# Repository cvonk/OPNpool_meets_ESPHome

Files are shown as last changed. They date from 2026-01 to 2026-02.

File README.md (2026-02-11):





> OPNpool Meets ESPHome has been merged with my [original OPNpool](https://github.com/cvonk/OPNpool) repo.  Please refer to that repo instead.

Ever dreamed of making your pool smarter and easier to manage? If you’ve ever owned a backyard pool, you know it’s not just about swimming—there’s a whole world of chemicals, covers, vacuums, brushes, and fiddling with thermostats and circuits. Even with a saltwater pool, you’ve got to keep a close eye on things!

Enter OPNpool: your pool’s new best friend. It takes all the classic pool controller features and brings them into your smart home. OPNpool keeps track of your controller, pump, and chlorinator, so you don’t have to run outside every time you want to check or change something. Even better, you can set up automations—like running the pump longer when it’s hot out—all from the comfort of your phone or smart home dashboard.

Thanks to some clever folks who reverse engineered the RS485 protocol, OPNpool can eavesdrop on the chatter between your pool’s components. The ESP32 inside shares all that state info as JSON/HTTP and can publish it via MQTT. And if you’re a Home Assistant fan, you’ll love how easily it integrates using MQTT Discovery.

# OPNpool meets ESPHome

OPNpool meets ESPHome is an open-source hardware and software solution that brings advanced pool automation to your smart home. By bridging legacy pool controllers with modern IoT platforms, OPNpool enables real-time monitoring, remote control, and seamless integration with Home Assistant. Whether you want to automate your pool pump based on temperature, monitor chlorinator status, or simply enjoy the convenience of remote access, OPNpool provides a robust and extensible platform for pool management.

## How it works

At its core, OPNpool connects an ESP32 microcontroller to your pool controller’s RS-485 bus. The ESP32 runs ESPHome firmware, which translates pool equipment data into Home Assistant entities. This allows you to view and control your pool’s thermostats, pumps, circuits, and chlorinator directly from your smart home dashboard or mobile app. The system is designed for reliability, safety, and ease of installation, with support for over-the-air updates and waterproof enclosures for outdoor use.

## Features

- [x] **Smart Home Integration:** Native support for Home Assistant and ESPHome.
- [x] **Remote Monitoring & Control:** Access your pool’s status and controls from anywhere.
- [x] **Community Driven:** Built on the work of pool automation enthusiasts and reverse engineers.
- [x] **Open Source:** Fully transparent hardware and software—customize and extend as needed.

## Getting started

No prior experience with pool automation or ESPHome is required. The documentation below will guide you through hardware assembly, wiring, firmware installation, and Home Assistant integration. If you have questions or need help, join the project’s GitHub Discussions for community support.

This device was tested with the Pentair SunTouch controller with firmware **2.080** (2013-07-15), connected to an IntelliFlo pump and IntelliChlor saltwater chlorinator.

> This open source and hardware project is intended to comply with the October 2016 exemption to the Digital Millennium Copyright Act allowing "good-faith" testing," in a controlled environment designed to avoid any harm to individuals or to the public.

## Acknowledgements

> We proudly acknowledge the work of reverse engineering pioneers [Joshua Bloch](https://docs.google.com/document/d/1M0KMfXfvbszKeqzu6MUF_7yM6KDHk8cZ5nrH1_OUcAc/edit), [Michael Russe](http://cocoontech.com/forums/files/file/173-pab014sharezip/), and [George Saw](http://cocoontech.com/forums/topic/27864-download-pitzip/). (Drop me a line if I forgot you.)

## Usage

Start with [installing the ESPHome environment](https://esphome.io/guides/installing_esphome/) on a beefy computer. In my case, this cut the compilation time to a minute, compared to half an hour when running it as an add-on to Home Assistant.

In an empty directory, create a `opnpool-1.yaml` configuration file as shown below.
```yaml
substitutions:
  device_name: opnpool-1
  friendly_name: "OPNpool meets ESPHome"
  description: "External component, see https://github.com/cvonk/OPNpool_meets_ESPHome"

esphome:
  name: ${device_name}
  comment: ${description}
  friendly_name: ${friendly_name}

esp32:
  variant: esp32c6          # or esp32     for <= r3 boards
  board: esp32-c6-devkitc-1 # or lolin_d32 for <= r3 boards
  framework:
    type: esp-idf

wifi:
  domain: !secret domain_name # only needed if not on the same subnet
  min_auth_mode: WPA2
  reboot_timeout: 0s
  networks:
  - ssid: !secret wifi_ssid
    password: !secret wifi_password

api:

ota:
  - platform: esphome
    password: !secret ota_password

external_components:
  - source: github://cvonk/OPNpool_meets_ESPHome
    components: [ opnpool ]

logger:
  level: VERBOSE          # build includes ESP_LOGx up to VERBOSE
  initial_level: WARN     # only show up to WARN globally
  logs:
    poolstate_rx: VERBOSE # show decoded messages

opnpool:
  id: opnpool_1
  RS-485:
    tx_pin:  21  # or 26 for <= r3 boards 
    rx_pin:  22  # or 25 for <= r3 boards
    rts_pin: 23  # or 27 for <= r3 boards
```

Specify your own secrets in `secrets.yaml`

```yaml
wifi_ssid: "REDACTED"
wifi_password: "REDACTED"
domain_name: ".iot.example.com" # appended to base fname to create FQDN for OTA updates
ota_password: "REDACTED"
api_encryption_key: "REDACTED"
```

Compile and upload the code using

```bash
esphome run opnpool-1.yaml
```

The first time, you need to upload over USB Serial, but after that you can use over-the-air updates.

In the output, you should see something like:

```text
[16:26:54.983]I (423) boot: Loaded app from partition at offset 0x10000
[16:26:55.024]I (465) boot: Set actual ota_seq=1 in otadata[0]
[16:26:55.029]I (465) boot: Disabling RNG early entropy source...
[16:26:55.268][W][component:333]: api set Warning flag: unspecified
[16:26:55.273][W][component:342]: wifi set Warning flag: scanning for networks
[16:27:01.293][W][component:373]: wifi cleared Warning flag
[16:27:25.143][E][RS-485:108][pool_req_task]: tx_q full
[16:27:55.144][E][RS-485:108][pool_req_task]: tx_q full
```

In the above trace, the `tx_q full` indicates that it can't transmit to the pool controller.

If you haven't already, add the ESPHome integration to Home Assistant.



Under Integrations, you will find now notice that Home Assistant auto discovered your new device.



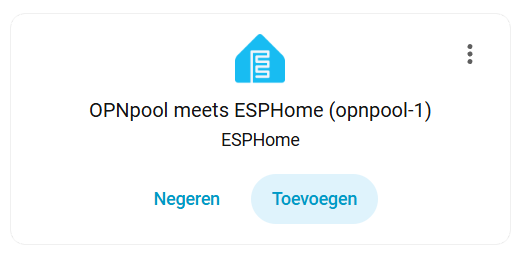
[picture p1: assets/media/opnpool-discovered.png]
Discovered


Add it, and specify your API key.  Name the device and assign it an area. You should then see the enities although their values are `unknown`.  Time to populate those entities by connecting it to the pool controller ;-)

## Connect

At the core this project is an ESP32 module and a 3.3 Volt RS-485 adapter. You can
breadboard this using:

* Any ESP32 module that has an USB connector and three GPIO pins available.
* Any "Max485 Module TTL". To make it 3.3 Volt compliant, change the chip to a `MAX3485CSA+`. While you're at it, you may as well remove the 10 kΩ pullup resistors (typically labeled `R1` to `R4`).
* A piece of Cat5 ethernet cable to connect to the pool controller.

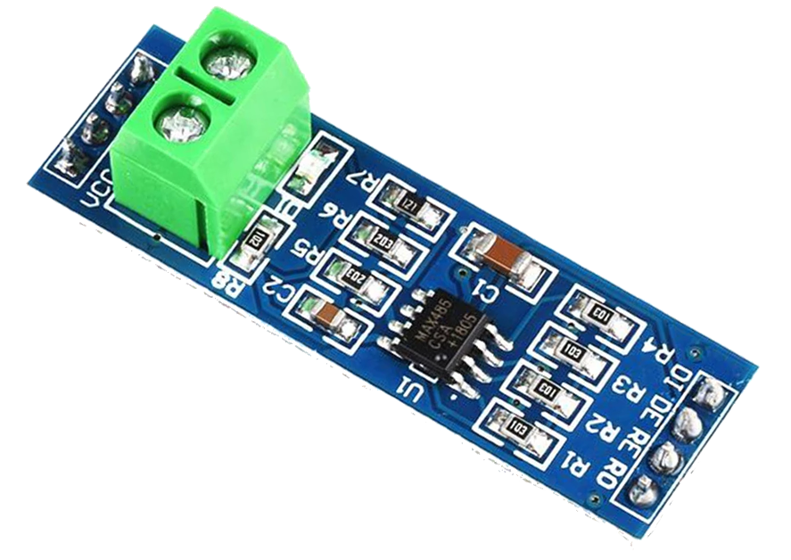
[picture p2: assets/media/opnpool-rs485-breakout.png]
Inside of Pool controller


If you prefer to make this a more permanent solution, I suggest rolling a printed circuit board and housing it in a IP68 waterproof case with IP68 connectors.  More about this later.

> :warning: **THIS PROJECT IS OFFERED AS IS. IF YOU USE IT YOU ASSUME ALL RISKS. NO WARRANTIES. At the very least, turn off the power while you work on your pool equipment. Be careful, THERE IS ALWAYS A RISK OF BREAKING YOUR POOL EQUIPMENT.**

Understanding the above warning .. the RS-485 header can be found on the back of the control board. There are probably already wires connected that go to the devices such as pump and chlorinator.

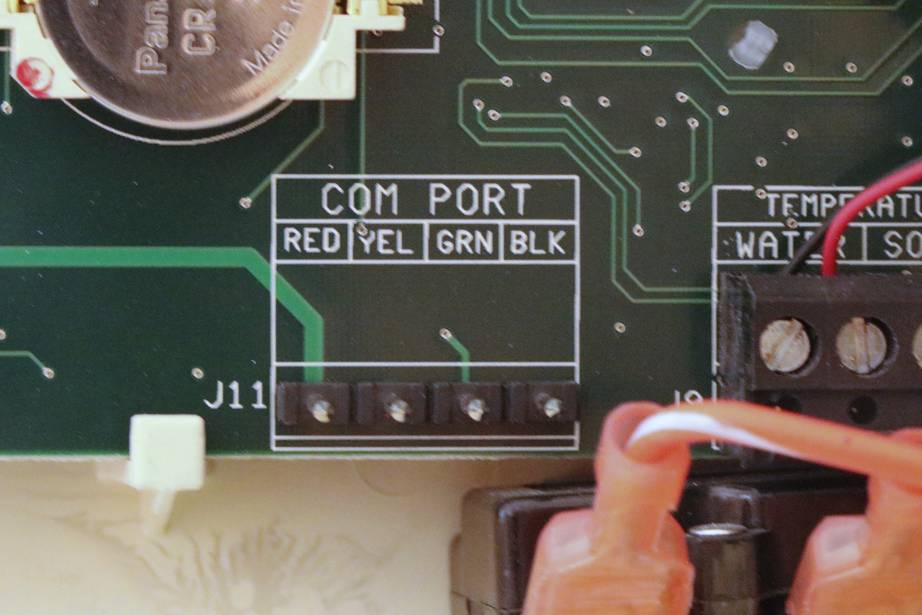
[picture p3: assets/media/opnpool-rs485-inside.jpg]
Inside of Pool controller


To minimize electromagnetic interference, use a twisted pairs from e.g. CAT-5 cable to connect the `A`/`B` pair to the RS-485 adapter as shown in the table below.

| Controller | RS-485 adapter | idle state | 
|:---|:---:|:---|
| `-DATA` (green)  |  `A` | negative |
| `+DATA` (yellow) |  `B` | positive |

Connect the RS-485 adapter to the ESP32 module.  I also pulled `GPIO#27` down with a 10 k&ohm; resistor, to keep it from transmiting while the ESP32 is booting.

| RS-485 adapter | ESP32 module |
|:---|:---|
| RO | `GPIO#25` |
| DI | `GPIO#26` |
| DE and RE | `GPIO#27` |
| GND | `GND` |

The serial monitor will start to show decoded messages such as:

```json
{CTRL_VERSION_REQ: {}}
{CTRL_VERSION_RESP: {"firmware":"2.80"}}
{CTRL_TIME_REQ: {}}
{CTRL_TIME_RESP: {"tod":{"time":"18:51","date":"2026-01-18"}}}
{CTRL_HEAT_REQ: {}}
{CTRL_HEAT_RESP: {"thermos":{"POOL":{"temp":54,"sp":63,"src":"NONE"},"SPA":{"temp":54,"sp"}
```

> :bulb: If you don't see such messages, make sure you didn't swap the data leads, or oddly enough some people report that they do need to swap the data leads.  To debug the datalink framing, set the `datalink_rx` logger level to `VERBOSE` and build and upload the code again. See futher below.

In Home Assistant the entities should populate, and show on your favorite Lovelace UI.

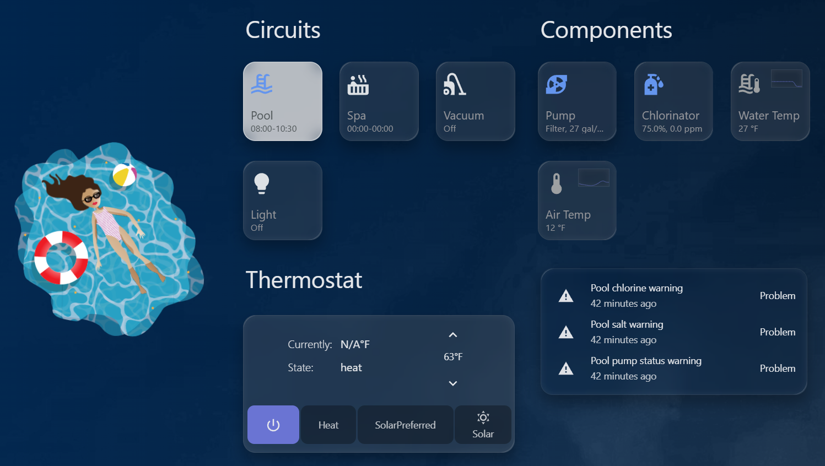
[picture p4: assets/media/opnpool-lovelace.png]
Lovelace_view


## PCB

For a robust and weatherproof installation, we recommend building a custom printed circuit board (PCB) to house the ESP32-C6 module, RS-485 adapter, and DC/DC converter. This approach ensures reliable connections, easier mounting, and long-term durability—especially for outdoor or poolside environments.

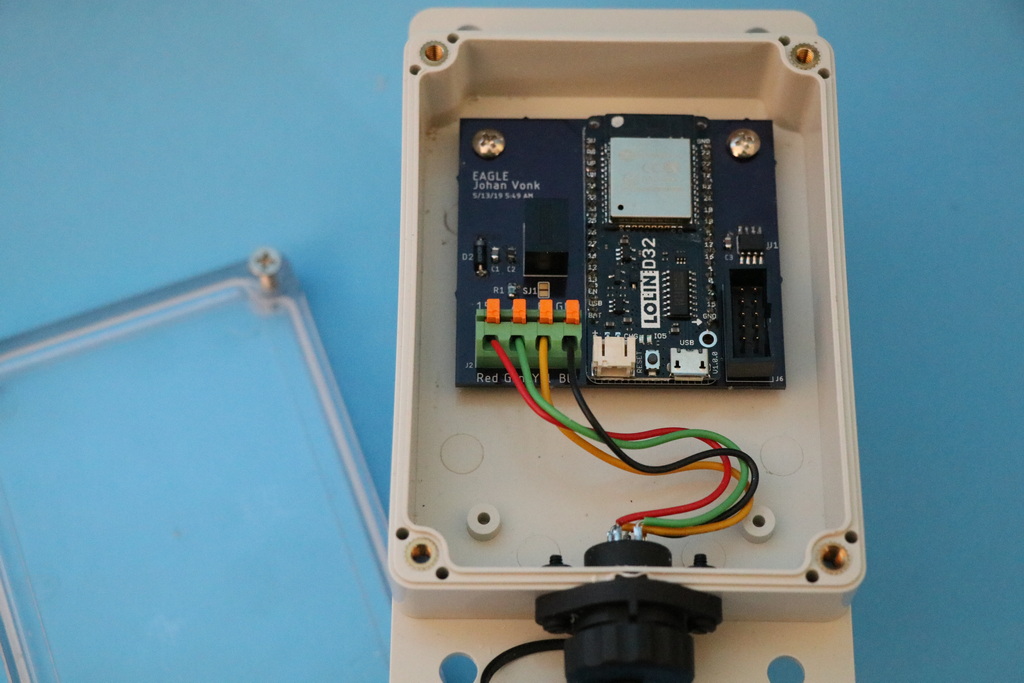
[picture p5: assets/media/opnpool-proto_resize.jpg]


Note that the photo above is from a rev 1 board.

### Schematic

The hardware design features a buck converter that supplies 5V to the `5V0` pin on the ESP32-C6 DevKitC-1-N8 daughterboard. The scotty diode prevent issues when the board is also powered via USB.

Schematic

The main data path runs between the RS-485 connector and the ESP32-C6 on the DevKitC-1-N8. An optional termination resistor is included to minimize signal reflections on the RS-485 bus.

### Board Layout

The entire schematic fits comfortably on a compact two-layer PCB. The board was designed using the free version of AutoDesk EAGLE, and all source files — including layout and schematics — are available in the [hardware directory](tree/main/hardware) of this repository.

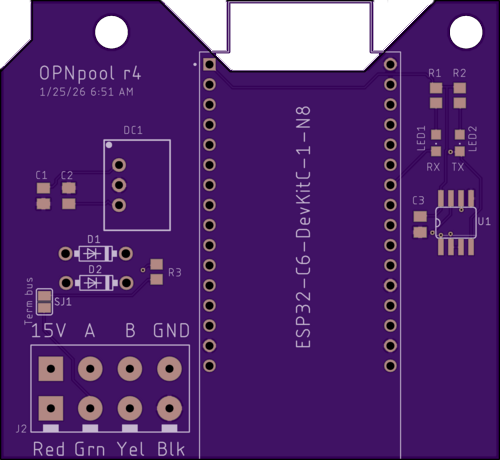
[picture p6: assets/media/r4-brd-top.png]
Board Layout


### Bill of materials

| Name | Description | Suggested mfr/part# | Price paid
|---|---|---|---
| PBC r4 | Printed circuit board | OSHPark | [$9.43](https://oshpark.com/)
| Enclosure | 158x90x60mm ABS Plastic Junction Box, IP65 | *white label* | [$9.81](https://www.harfington.com/products/p-1159792)
| RS-485_CONN | 5P Plug+socket, 5-pin, 16mm aviation, IP68 | SP16 5P | [$3.98](https://www.aliexpress.us/item/2251832722757291.html)
| RS-485-TERM | Fixed terminal block, 4-pin, screwless, 5 mm pitch | Phoenix-Contact 1862437 | [$2.02](https://www.digikey.com/en/products/detail/phoenix-contact/1862437/6605421)
| ESP32-C6 DevKitC-1-N8 | ESP32-C6 dev board with 8MB flash, based on ESP32-C6-WROOM | ESP32-C6 DevKitC-1-N8 | [$9.00](https://www.digikey.com/en/products/detail/espressif-systems/ESP32-C6-DEVKITC-1-N8/17728861)
| MAX3485 | Maxim MAX3485CSA, RS-485/UART interface IC 3.3V, 8-SOIC  | Analog-Devices MAX3485CSA+T | [$5.64](https://www.digikey.com/en/products/detail/analog-devices-inc-maxim-integrated/MAX3485CSA-T/1703654)
| DC1 | DC/DC Converter R-78E5.0-0.5, 7-28V to 5V, 0.5A, 3-SIP | RECOM-Power R-78E5.0-0.5 | [$3.30](https://www.digikey.com/en/products/detail/recom-power/R-78E5-0-0-5/2834904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)
| D1, D2 | Schottky Diode, 1N5818, 30V, 1A, DO-41 | Diodes Incorporated 1N5818-T | [$0.30](https://www.digikey.com/en/products/detail/diodes-incorporated/1N5818-T/22054)
| LED1 | LED, Green Clear 571nm, 1206 | Lite-On LTST-C150KGKT | [$0.15](https://www.digikey.com/en/products/detail/diodes-incorporated/1N5818-T/22054)
| LED2 | LED, Amber Clear 602nm, 1206 | Lite-On LTST-C150AKT | [$0.15](http2s://www.digikey.com/en/products/detail/liteon/LTST-C150AKT/269213?s=N4IgTCBcDaIDIEsAuBTAtAeQHYAI4BUBlfNAYQEYBWABgEEBpfEAXQF8g)
| C1, C2 | Capacitor, 10 µF, 25 V, multi-layer ceramic, 0805 | KEMET C0805C106K3PACTU | [$0.22](https://www.digikey.com/en/products/detail/kemet/C0805C106K3PACTU/5267604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)
| C3 | Capacitor, 0.1 µF, 6.3 V, multi-layer ceramic, 0805 | KEMET C0805C104M3RACTU | [$0.12](https://www.digikey.com/en/products/detail/kemet/C0805C104M3RACTU/2211748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)
| R1, R2 | Resistor, 68 Ω, 1/8 W, 0805 | YAGEO RC0805FR-0768RL | [$0.20](https://www.digikey.com/en/products/detail/yageo/RC0805FR-0768RL/728097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)
| R3 | Not stuffed, resistor, 120 Ω, 1/4 W, 0805 | KAO SG73S2ATTD121J | [$0.00](https://www.digikey.com/en/products/detail/koa-speer-electronics-inc/RK73B2ATTD121J/10236600)
| PCB Screws  | Machine screw, #6-32 x x 3/16", panhead | Keystone-Electronics 9306  | [$0.10](https://www.digikey.com/en/products/detail/keystone-electronics/9306/2746085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)
| CONN Screws | Machine screw, M2-0.4 x 16 mm, cheese head | Essentra 50M020040D016 | [$0.28](https://www.digikey.com/en/products/detail/essentra-components/50M020040D016/11639297)
| CONN Nuts | Hex nut, M2-0.4, nylon | Essentra 04M020040HN | [$0.15](https://www.digikey.com/en/products/detail/essentra-components/04M020040HN/9677098)

Note that tariffs and shipping will add to the cost.

## Troubleshooting

Not all controller firmwares are created equally.  If you are not using firmware version 2.080, you will need dive down to the byte level and to tweak the network layer.  If you succeed, please send me an pull request, and I will iinclude it in the next release.

To show more (or less) debug information, specify the levels in `opnpoool-1.yaml`

```yaml
logger:
  level: VERBOSE       # build includes ESP_LOGx up to VERBOSE
  initial_level: WARN  # only show up to WARN globally
  logs:
    rs485: WARN
    datalink_rx: WARN
    datalink_tx: WARN
    network_rx: WARN
    network_create: WARN
    pool_task: WARN
    ipc: WARN
    poolstate: WARN
    poolstate_rx: VERBOSE
    opnpool: WARN
    opnpool_climate: WARN
    opnpool_switch: WARN
    opnpool_sensor: WARN
    opnpool_binary_sensor: WARN
    opnpool_text_sensor: WARN
    enum_helpers: WARN
```

For the `logger` component, it is recommended to use the following levels: `WARN`, which shows only warnings and errors; `INFO`, which includes informational messages such as configuration details, warnings, and errors; and `VERBOSE`, which provides very detailed logs, info, warnings, and errors. Be careful not to enable too much logging, as excessive output can negatively impact the connection between Home Assistant and the ESP32-C6.

### Decoding Stack Traces

If your ESP32-C6 crashes and you notice stack traces in the serial log, you can simplify debugging by enabling ESPHome's stack trace decoder. With this feature, exception addresses are automatically translated into human-readable function names and line numbers within your logs.

To activate the stack trace decoder, add the following lines to your YAML configuration:

```yaml
debug:
  update_interval: 5s  # for exception decoding in logs
```

> **Tip:** Detailed crash information will only appear on the serial console (not in the web logs). Be sure to check the serial output for troubleshooting.

# FAQ

**LEDs not blinking with RS-485 connected**

If communication fails, swap the `-DATA` and `+DATA` wires, as standards for these labels vary. 

**Is a controller required?**

This setup ensures that when selling the house, the next owner is not stuck with a "custom" system. They can use the pool conventionally or easily adopt the smart features.  If you're determined to build your own controller, I can recommend Russ Goldin's [nodejs-poolController](https://github.com/tagyoureit/nodejs-poolController/tree/master).

**Will it work with ___ board?**

There are many boards and kits that incorporate the ESP32. I started with the ESP8266, switched to the original ESP32, and use the ESP-C6. At this point it probably runs on any ESP32 flavor board. If you want to try something else, sure feel free the code is written to be portable. Just make sure you use the MAX3485 instead of the TTL-level MAX485.

**My firmware is ___ How do you update SunTouch firmware?**

Instead of taking such a risky step, I recommend enabling `VERBOSE` logging for `datalink_rx` and `network_rx`.  This will visualize the raw bytes received and messages interpretated. Compare that with the structures `network_msg.h`, and update the file as needed.

> Only do this if you very confident with flashing electronics. You risk bricking your pool controller.

Having read the above warning, you can upgrade if your controller is at [version 2.x](https://saturationregion.blogspot.com/2020/01/whats-deal-with-easytouch-versions-1.html). You will need to get a [USBDM JS16](https://www.aliexpress.us/w/wholesale-Freescale-USBDM-Programmer-JS16.html?spm=a2g0o.detail.search.0) programmer, [make](https://www.troublefreepool.com/threads/how-to-perform-firmware-upgrade-on-pentair-controllers.69589/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) a [JST cable](https://www.aliexpress.us/w/wholesale-5-PCS-JST-1.-25mm-Male-Female-6p.html?spm=a2g0o.detail.search.0) following [the instructions](https://www.troublefreepool.com/threads/how-to-perform-firmware-upgrade-on-pentair-controllers.69589/page-7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).

#
I hope this project brings you joy.  Keep in touch through the dicussion forum.

Coert

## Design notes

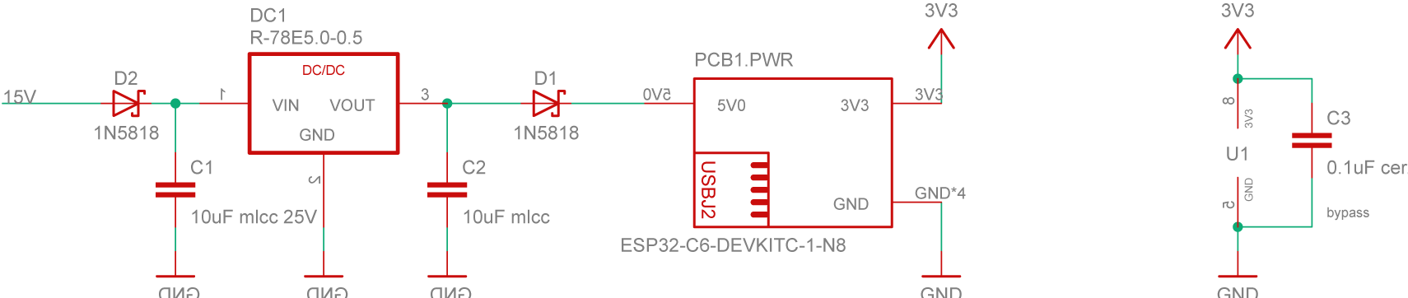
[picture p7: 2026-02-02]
assets/media/schematic-r4-pwr.png

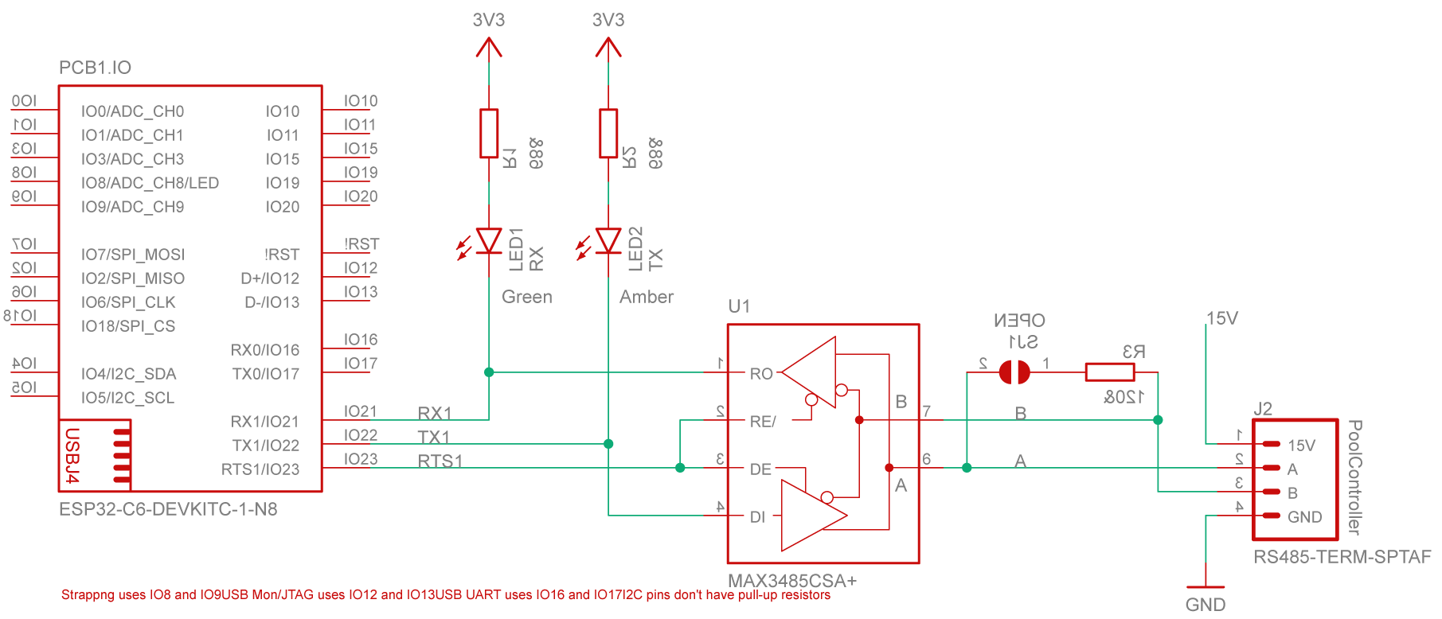
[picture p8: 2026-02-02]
assets/media/schematic-r4-io.png

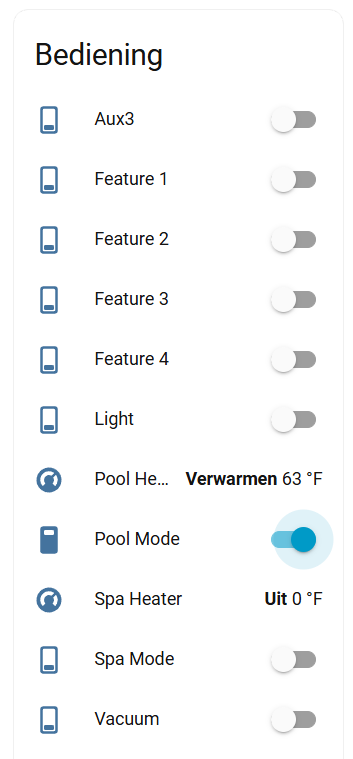
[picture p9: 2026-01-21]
assets/media/opnpool-bediening.png

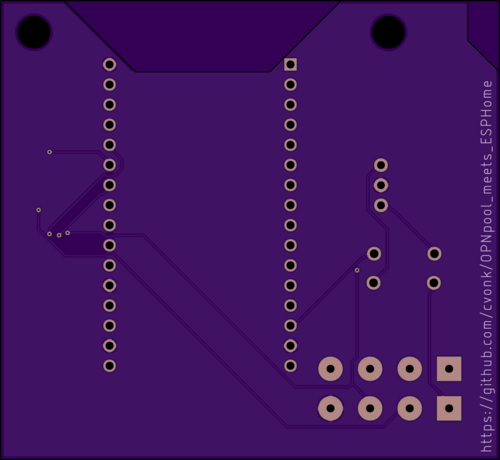
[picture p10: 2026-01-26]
assets/media/r4-brd-bottom.png

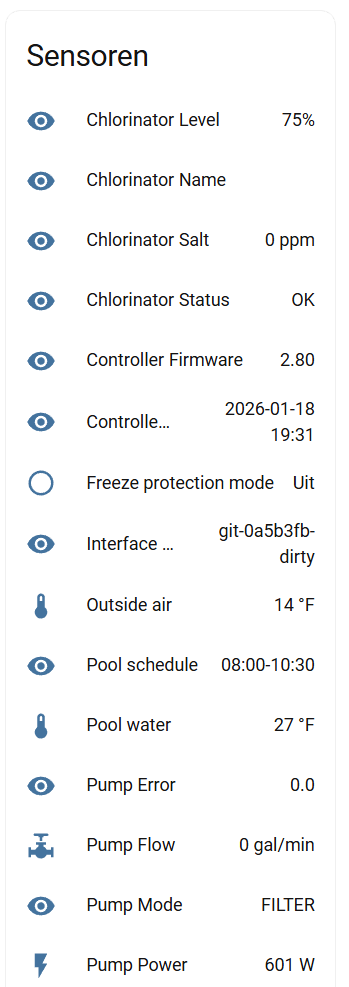
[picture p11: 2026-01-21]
assets/media/opnpool-sensoren.png

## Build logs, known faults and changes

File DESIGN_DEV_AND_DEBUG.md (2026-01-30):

# Design, development and debugging

This software is designed for robustness, reliability, and long-term maintainability. The architecture emphasizes modularity and extensibility through protocol abstraction helpers and FreeRTOS primitives for cooperative task scheduling and inter-task communication. Comprehensive logging enables diagnostics, troubleshooting, and protocol analysis.

## Design

ESPHome provides a single-threaded environment, so explicit thread safety measures are not required.

### Protocol stack

The software follows a layered architecture where each component builds upon the one below it, creating a clean path from raw electrical signals to Home Assistant entities. Here's how data flows through the system:

1. **MAX3485CSA+** — At the physical layer, this integrated circuit performs the critical job of converting between the ESP32's logic-level signals and the differential signaling used by RS-485. This conversion enables robust, noise-resistant communication over long twisted-pair cable runs to your pool equipment.

2. **UART** — The ESP32's Universal Asynchronous Receiver/Transmitter bridges the gap between bit streams and bytes. It frames each byte with start and stop bits, manages precise timing at the configured baud rate, and delivers clean byte streams to the software layers above.

3. **RS-485 driver** — This layer wraps the UART hardware with a practical interface for half-duplex RS-485 communication. Beyond basic UART configuration and GPIO control, it maintains a transmit queue for outgoing packets and exposes function pointers that let higher layers easily interact with the bus. The driver's two essential operations are reading incoming bytes and queueing outgoing byte streams for transmission.

4. **Data Link Layer (DLL)** — Here's where raw bytes become structured packets. On reception, the DLL strips headers and tails from RS-485 byte streams and validates their integrity. On transmission, it wraps outgoing data with the proper framing to ensure packets arrive intact.

5. **Network Layer** — This layer speaks the pool controller's language, translating between raw datalink packets and meaningful network messages. Incoming packets become structured messages the application can understand; outgoing messages get encapsulated into properly formatted datalink packets ready for the wire.

6. **PoolState** — Think of this as the software's digital twin of your pool system. This class maintains a complete model of the pool controller and all its peripherals—pump, chlorinator, circuits, sensors, and more. Every incoming network message updates this state, keeping it synchronized with the actual equipment. This real-time model forms the foundation for all sensor readings and control operations.

7. **OpnPool** — The final layer bridges the protocol stack to the ESPHome world. It continuously synchronizes the PoolState with ESPHome entities, ensuring your Home Assistant dashboard accurately reflects your pool's status. When you flip a switch or adjust the temperature in Home Assistant, this layer translates your intent into commands for the pool controller. Conversely, it publishes state changes as updates to climate controls, switches, sensors, binary sensors, and text sensors.

### Tasks

Rather than cramming everything into a single execution thread, the software leverages FreeRTOS to divide responsibilities between two cooperative tasks that communicate through message-passing mailboxes:

* The **main task** orchestrates the high-level application logic, running OpnPool and PoolState to manage state and interact with ESPHome.
* The **pool task** handles the nitty-gritty details of RS-485 communication, protocol parsing, and network message processing. It even spawns its own helper task dedicated to periodically requesting updates from the pool controller.

This separation keeps low-level communication concerns isolated from application logic, making the codebase easier to reason about and maintain.

### More info

Want to dive deeper into the protocol and architecture? The [original OPNpool project](https://github.com/cvonk/OPNpool) has comprehensive design documentation that applies equally well to this ESPHome port:

- [OPNpool Design Documentation Overview](https://coertvonk.com/category/sw/embedded/opnpool-design)

These chapters are particularly relevant:

- [RS-485 bus](https://coertvonk.com/sw/embedded/opnpool-design/bus-access-31957) — Low-level bus access and timing
- [Hardware](https://coertvonk.com/sw/embedded/opnpool-design/hardware-3-31959) — Circuit design and interfacing
- [Protocol](https://coertvonk.com/sw/embedded/opnpool-design/protocol-31965) — Message format and state machine details

## Development

For the best development experience, install the C/C++ and [ESPHome extension](https://marketplace.visualstudio.com/items?itemName=ESPHome.esphome-VSCode) in VS Code.

Clone the repository to a local directory:
```bash
git clone https://github.com/cvonk/OPNpool_meets_ESPHome.git
```

Or using SSH:
```bash
git clone git@github.com:cvonk/OPNpool_meets_ESPHome.git
```

The included `tasks.json` file provides pre-configured build and upload tasks that integrate seamlessly with VS Code. Build output maps directly to your project files, letting you jump straight to errors and warnings from the `Problems` tab.

**Common shortcuts:**

- **Build:** <kbd>Ctrl</kbd>+<kbd>Shift</kbd>+<kbd>B</kbd> (or <kbd>Cmd</kbd>+<kbd>Shift</kbd>+<kbd>B</kbd> on Mac)
- **Compile & Upload:** <kbd>Ctrl</kbd>+<kbd>Shift</kbd>+<kbd>P</kbd> → "Run Task" → "ESPHome Upload opnpool-1"
- **Clean:** <kbd>Ctrl</kbd>+<kbd>Shift</kbd>+<kbd>P</kbd> → "Run Task" → "ESPHome Clean opnpool-1"
- **View Logs:** <kbd>Ctrl</kbd>+<kbd>Shift</kbd>+<kbd>P</kbd> → "Run Task" → "ESPHome Logs opnpool-1"

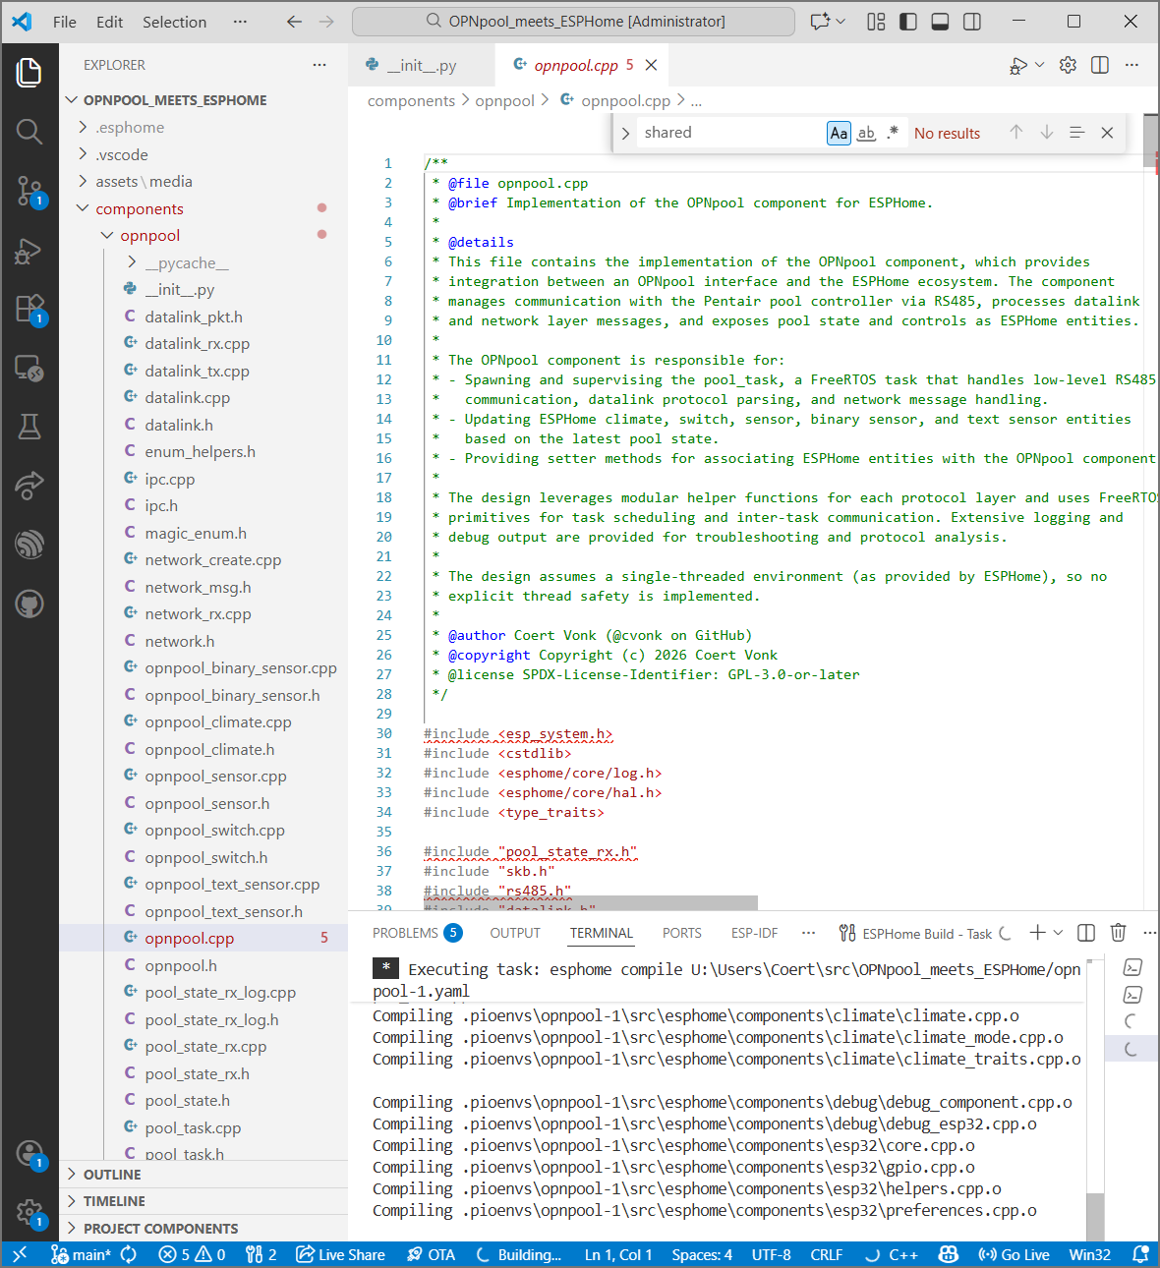
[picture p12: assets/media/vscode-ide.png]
VSCode_ide


## JTAG debugging (on &ge; r4 boards)

The newer r4 boards feature the ESP32-C6 module with built-in JTAG debugging capability. This eliminates the need for external debugging hardware—just connect directly via USB. The configuration is straightforward:

```
build_type = debug
monitor_speed = 115200
debug_tool = esp-builtin
debug_init_break = tbreak setup ; or e.g. app_main
```

You may also want to disable optimizations for clearer debugging:
```
debug_build_flags = -O0 -g -ggdb
```

On Windows, Zadig might need to reassign Interface 2 to WinUSB 6.xx for proper operation.

## JTAG debugging (on &le; r3 boards)

While `ESP_LOGx` logging serves its purpose, it traps you in an endless cycle of adding print statements, recompiling, uploading, and hoping you logged the right thing. JTAG debugging with GDB breaks this cycle completely. You get direct, real-time access to your ESP32's internal state—set breakpoints anywhere, inspect the full call stack, examine local variables, and watch memory locations change, all without modifying a single line of code or recompiling.

Memory corruption bugs that take hours to track down with logging? Set a watchpoint on the corrupted address and GDB will halt execution the instant something writes to it, showing you exactly what code is responsible. This is the difference between guessing and knowing—JTAG transforms ESP32 development from a frustrating debug-by-printf experience into professional source-level debugging.

### ESP-Prog

The ESP-Prog is your gateway to JTAG debugging on r3 and earlier boards. This compact debugging tool connects the 10-pin JTAG header on your OPNpool PCB to your computer, unlocking hardware-level debugging and programming capabilities that simply aren't available through the standard USB serial connection.

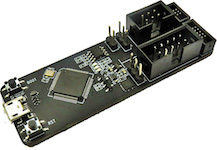
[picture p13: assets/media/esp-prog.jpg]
ESP-Prog


Beyond debugging, the ESP-Prog can also flash firmware and provide serial communication—meaning you can disconnect your regular USB cable entirely during debug sessions.

At its heart, the ESP-Prog uses an FTDI FT2232HL chip that exposes two independent USB channels: one for JTAG and another for serial communication. Getting started requires installing the FTDI driver per the [PlatformIO instructions](https://docs.platformio.org/en/stable/plus/debug-tools/esp-prog.html#drivers)—read them carefully, as there's a crucial driver modification step.[^1]

[^1]: The driver exposes both channels as serial ports. Channel 1 handles standard serial communication, while channel 0 serves JTAG. For JTAG to work, you must unload the serial driver from channel 0—on Windows, this means using Zadig to replace the FTDI driver with the Microsoft WinUSB generic driver.

### VSCode

Start by cloning the code from GitHub and performing a regular compile as described in the Development section. This generates a PlatformIO build directory at `.esphome/build/opnpool-1` containing all the generated C++ code, component sources, and ESPHome dependencies.

Open a fresh VS Code window and install the `PlatformIO IDE` extension if you haven't already. Navigate to the `.esphome/build/opnpool-1` folder and open it in VS Code. Then append these configuration lines to your `platformio.ini` file:

```
build_type = debug
monitor_speed = 115200
debug_init_break = tbreak setup
debug_tool = custom
debug_port = localhost:3333
```

Give VS Code a moment to update its metadata—proceeding too quickly will trigger a "Could not find the specified task" error. Once ready, connect your ESP-Prog to the computer and attach the 10-pin ribbon cable to the OPNpool PCB (keep the cable short to minimize signal integrity issues).

> **Note:** Theoretically, `debug_tool = esp-prog` should work without the `custom` override and manual OpenOCD startup. In practice, you'll likely encounter `.pioinit:11: Error in sourced command file` errors. The `.pioinit` file is auto-generated with target-specific defaults, and PlatformIO's automatic configuration doesn't always get it right.

OpenOCD (Open On-Chip Debugger) acts as the bridge between your IDE and the ESP32 hardware. Launch it manually and wait for the connection to establish:

```bash
cd ".platformio\packages\tool-openocd-esp32\bin"
./openocd -f board/esp32-wrover-kit-3.3v.cfg
```

Now for the fun part. Open the source file you want to debug in VS Code and click next to a line number to set a breakpoint—you'll see a red circle appear. For this example, we'll break in the PoolState constructor.

Click the "Run and Debug" icon in the activity bar, then hit the green play button in the top-left corner. Watch the `Terminal` panel as compilation proceeds. Once complete, switch to the `Debug Console` and wait while it connects to OpenOCD and loads all the symbolic debugging information.

When everything's ready, you'll see something like:

```
Thread 2 "loopTask" hit Temporary breakpoint 1.15, setup () at src/main.cpp:67
67	void setup() {
```

You're now wielding the full power of GDB. Inspect variables, navigate the call stack, and use the `Debug` view to explore program state interactively. Want to catch memory corruption? Set a watchpoint on the specific address you suspect is being corrupted:

```gdb
print &last_
   $4 = (esphome::opnpool::poolstate_t *) 0x3ffc19c0
watch *(0x3ffc19c0)
   Hardware watchpoint 4: *(0x3ffc19c0)
continue
```

Execution will halt the instant anything writes to that memory location, showing you exactly what code is responsible. This is debugging as it should be.

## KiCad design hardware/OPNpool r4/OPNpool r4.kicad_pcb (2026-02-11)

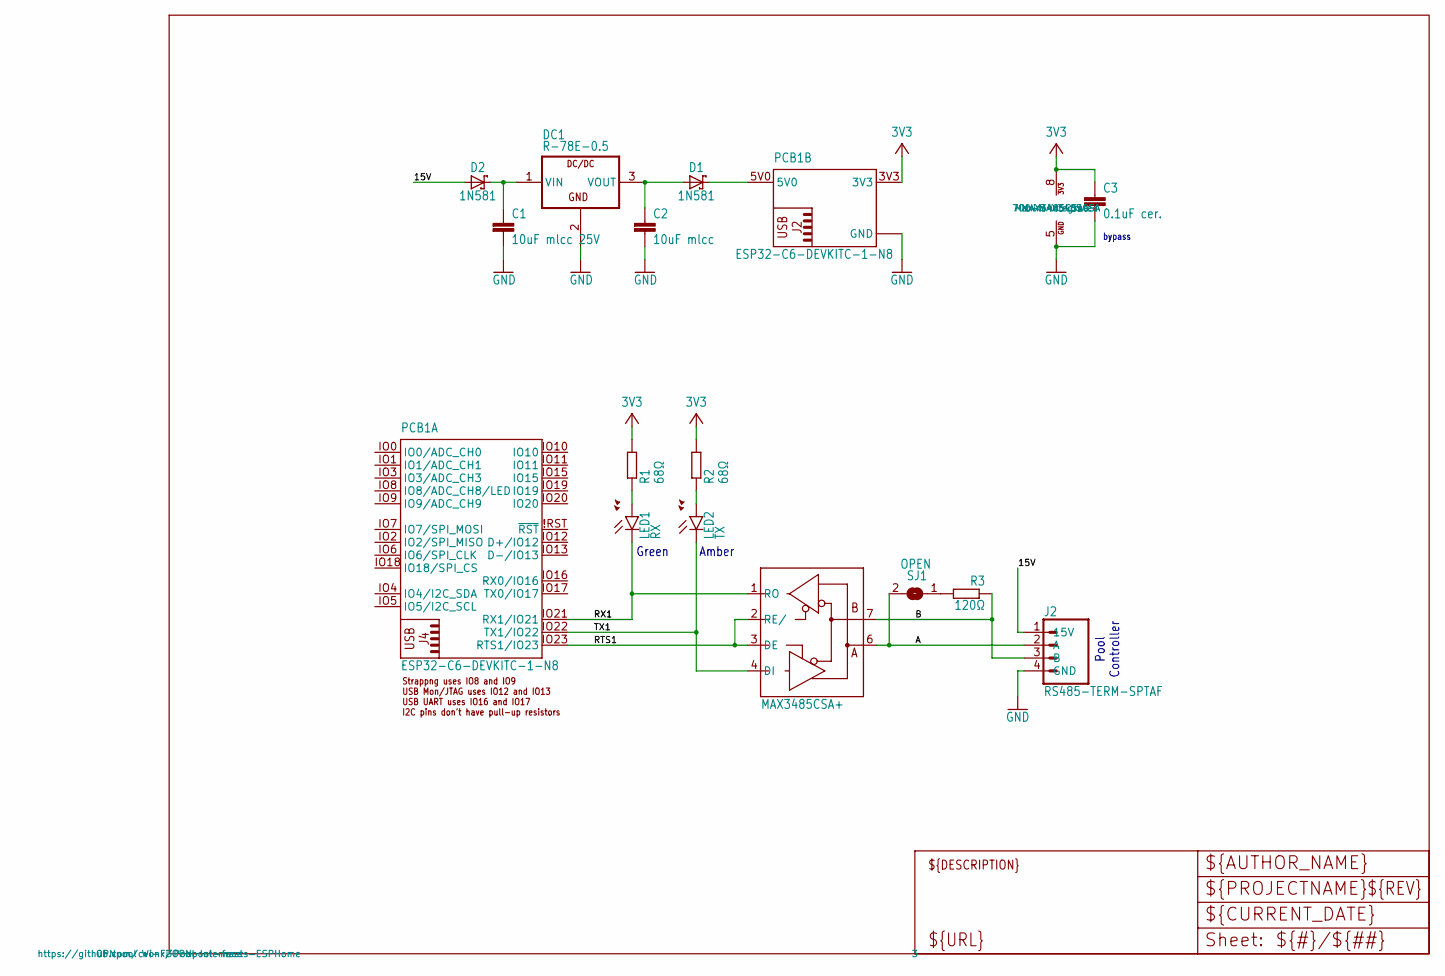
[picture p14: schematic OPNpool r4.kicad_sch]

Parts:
C1: 10uF mlcc 25V; C0805K; MOUSER# 81-GJ821BR61E106KE1L
C2: 10uF mlcc; C0805K; MOUSER# 81-GJ821BR61E106KE1L
C3: 0.1uF cer.; C0805K; MOUSER# 80-C0805C104K1REAUTO
D1, D2: 1N581; DO41-7.6; MOUSER# 583-1N5818-T
DC1: R-78E-0.5; SIP3; MOUSER# 919-R-78E5.0-0.5
J2: RS485-TERM-SPTAF; SPTAF1_4-5,0-LL; MOUSER# 651-1864451
LED1: RX; CHIPLED_0805
LED2: TX; CHIPLED_0805
PCB1: ESP32-C6-DEVKITC-1-N8; MODULE_ESP32-C6-DEVKITC-1-N8
R1, R2: 68Ω; R0805; MOUSER# 652-CRM0805JW1R5ELF
R3: 120Ω; R0805; MOUSER# 652-CRM0805JW1R5ELF
SJ1: OPEN; SJ
U1: MAX3485CSA+; SO08; MOUSER# 700-MAX3485CSA

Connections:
3V3: C3.1, PCB1.3V3, R1.2, R2.2, U1.8 (VCC)
15V: D2.A, J2.1 (15V)
A: J2.2 (A), SJ1.2, U1.6 (A)
B: J2.3 (B), R3.1, U1.7 (B)
GND: C1.2, C2.2, C3.2, DC1.2 (GND), J2.4 (GND), PCB1.GND, PCB1.GND@1 (GND), PCB1.GND@2 (GND), PCB1.GND@3 (GND), U1.5 (GND)
unnamed: LED1.A, R1.1
unnamed: LED2.A, R2.1
unnamed: D1.C, PCB1.5V0
unnamed: R3.2, SJ1.1
RTS1: PCB1.IO23 (RTS1/IO23), U1.2 (RE/), U1.3 (DE)
RX1: LED1.C, PCB1.IO21 (RX1/IO21), U1.1 (RO)
TX1: LED2.C, PCB1.IO22 (TX1/IO22), U1.4 (DI)
VIN: C1.1, D2.C, DC1.1 (VIN)
VOUT: C2.1, D1.A, DC1.3 (VOUT)

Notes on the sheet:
bypass
Pool Controller
Green
Amber

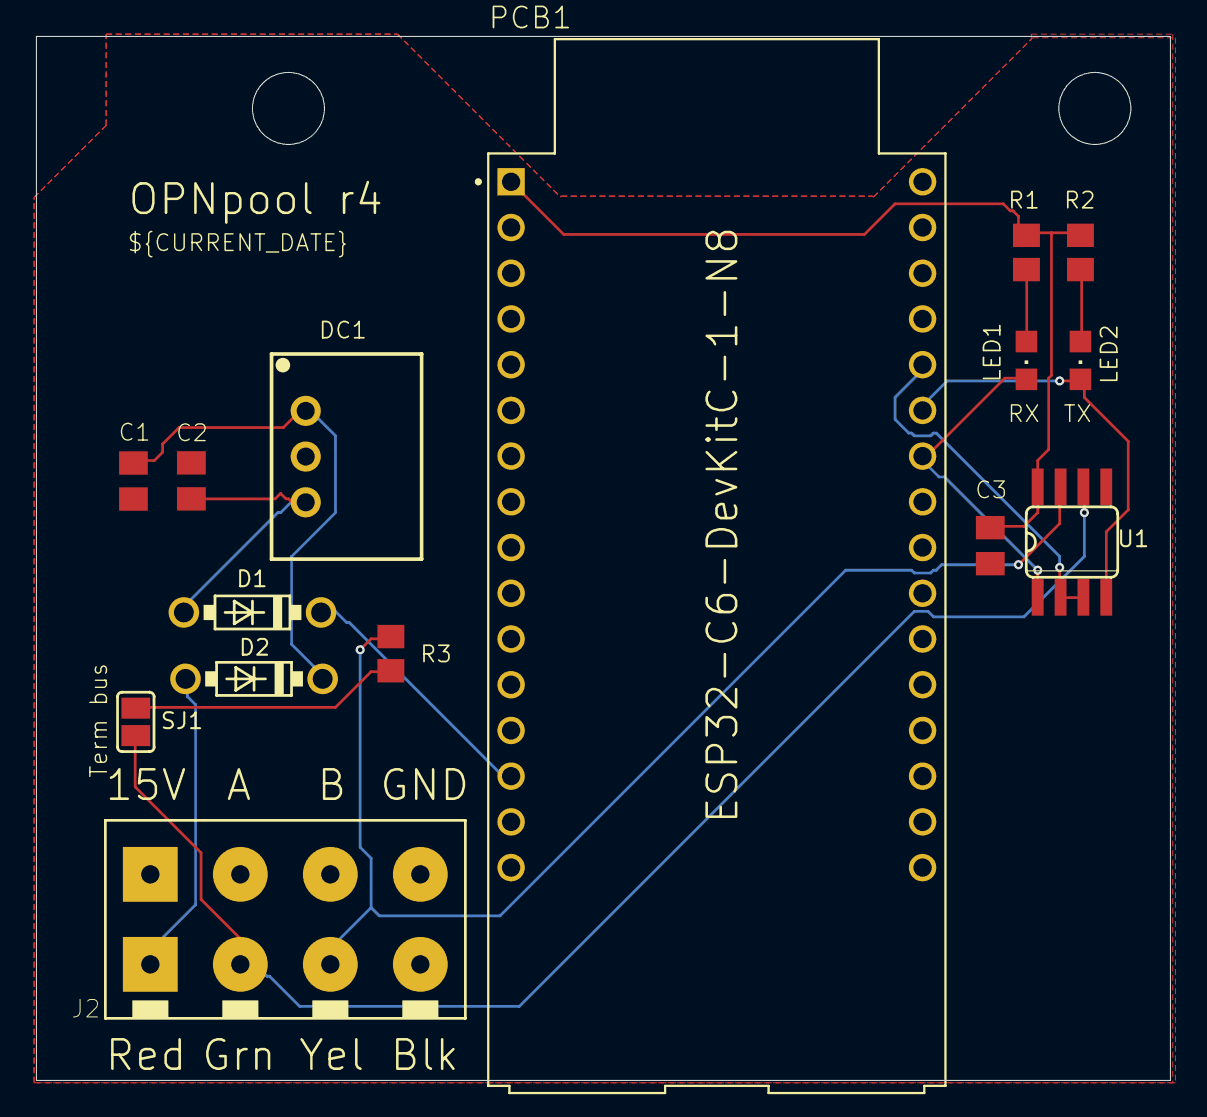
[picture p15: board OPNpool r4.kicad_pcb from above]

Board: 2 copper layers, 63.0 x 58.0 mm, 17 parts (0 on the bottom side), 14 nets.

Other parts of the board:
UNK_HOLE_0: dummyfp0
UNK_HOLE_1: dummyfp1

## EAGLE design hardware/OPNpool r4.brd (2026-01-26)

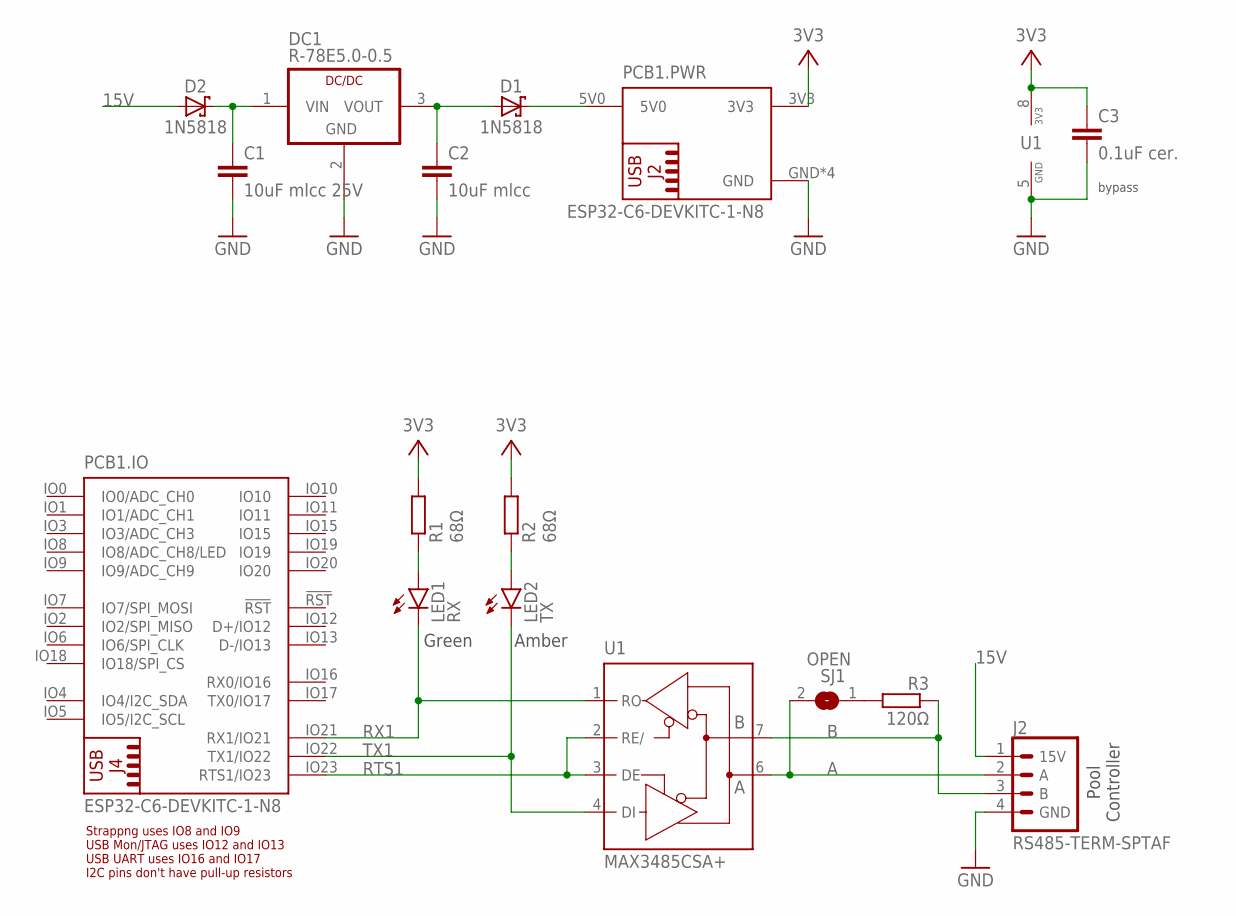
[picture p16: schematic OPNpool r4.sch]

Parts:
C1: 10uF mlcc 25V; C0805K; MOUSER# 81-GJ821BR61E106KE1L
C2: 10uF mlcc; C0805K; MOUSER# 81-GJ821BR61E106KE1L
C3: 0.1uF cer.; C0805K; MOUSER# 80-C0805C104K1REAUTO
D1, D2: 1N5818; DO41-7.6; MOUSER# 583-1N5818-T
DC1: R-78E5.0-0.5; SIP3; MOUSER# 919-R-78E5.0-0.5
J2: RS485-TERM-SPTAF; SPTAF1/4-5,0-LL; MOUSER# 651-1864451
LED1: RX; CHIPLED_0805
LED2: TX; CHIPLED_0805
PCB1: ESP32-C6-DEVKITC-1-N8; MODULE_ESP32-C6-DEVKITC-1-N8
R1, R2: 68Ω; R0805; MOUSER# 652-CRM0805JW1R5ELF
R3: 120Ω; R0805; MOUSER# 652-CRM0805JW1R5ELF
SJ1: OPEN; SJ
U1: MAX3485CSA+; SO08; MOUSER# 700-MAX3485CSA

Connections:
3V3: C3.1, PCB1.3V3, R1.2, R2.2, U1.8 (VCC)
15V: D2.A, J2.1 (15V)
A: J2.2 (A), SJ1.2, U1.6 (A)
B: J2.3 (B), R3.1, U1.7 (B)
GND: C1.2, C2.2, C3.2, DC1.2 (GND), J2.4 (GND), PCB1.GND, PCB1.GND@1 (GND), PCB1.GND@2 (GND), PCB1.GND@3 (GND), U1.5 (GND)
unnamed: LED1.A, R1.1
unnamed: LED2.A, R2.1
unnamed: D1.C, PCB1.5V0
unnamed: R3.2, SJ1.1
RTS1: PCB1.IO23 (RTS1/IO23), U1.2 (RE/), U1.3 (DE)
RX1: LED1.C, PCB1.IO21 (RX1/IO21), U1.1 (RO)
TX1: LED2.C, PCB1.IO22 (TX1/IO22), U1.4 (DI)
VIN: C1.1, D2.C, DC1.1 (VIN)
VOUT: C2.1, D1.A, DC1.3 (VOUT)

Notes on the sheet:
Pool Controller
bypass
Green
Amber

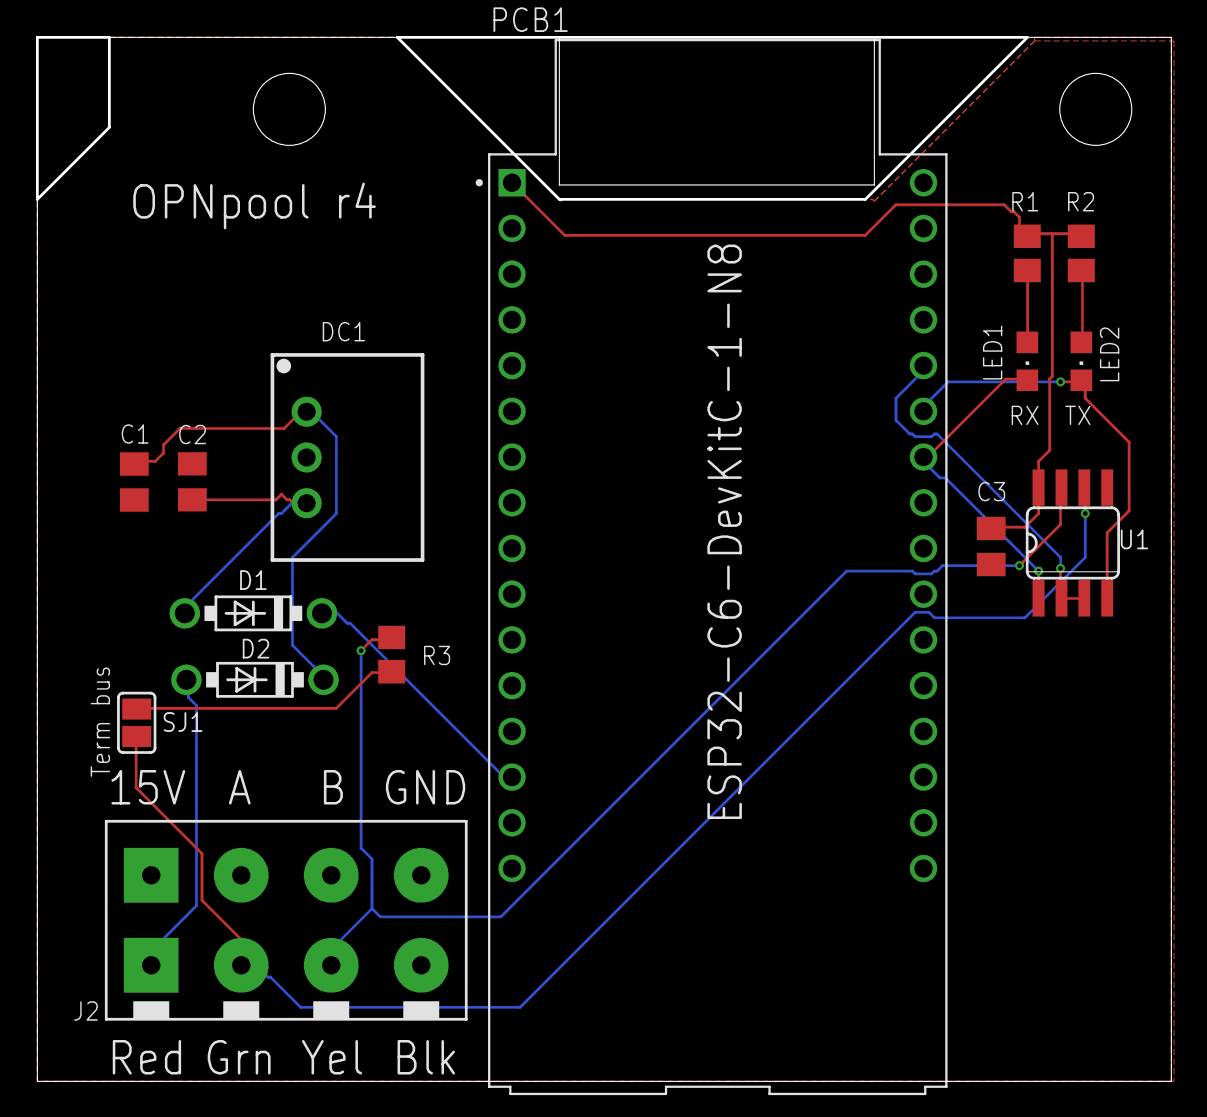
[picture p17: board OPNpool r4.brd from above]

Board: 2 copper layers, 63.0 x 58.0 mm, 15 parts (0 on the bottom side), 14 nets.

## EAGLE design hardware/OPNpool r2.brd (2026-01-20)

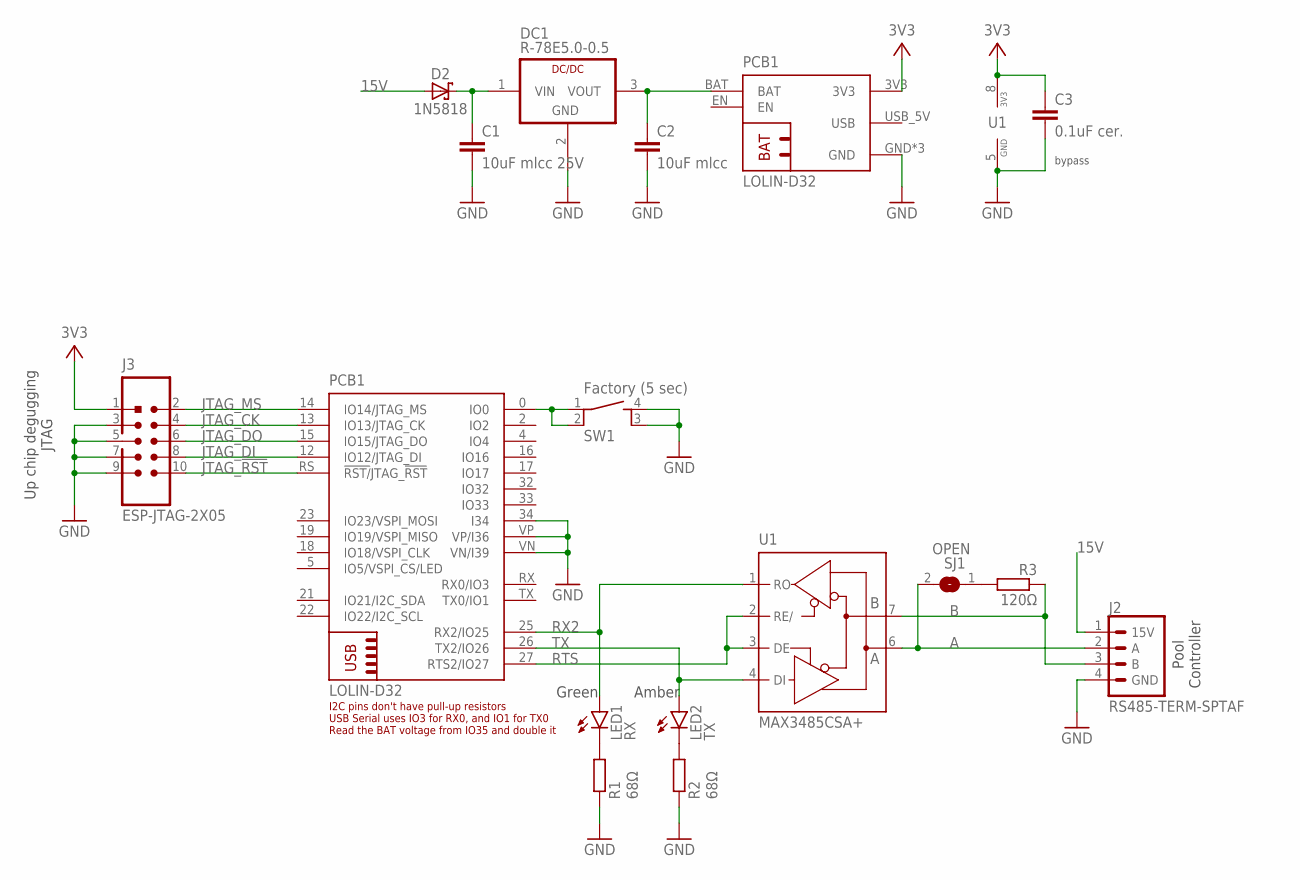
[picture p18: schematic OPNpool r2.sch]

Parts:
C1: 10uF mlcc 25V; C0805K; MOUSER# 81-GJ821BR61E106KE1L
C2: 10uF mlcc; C0805K; MOUSER# 81-GJ821BR61E106KE1L
C3: 0.1uF cer.; C0805K; MOUSER# 80-C0805C104K1REAUTO
D2: 1N5818; DO41-7.6; MOUSER# 583-1N5818-T
DC1: R-78E5.0-0.5; SIP3; MOUSER# 919-R-78E5.0-0.5
J2: RS485-TERM-SPTAF; SPTAF1/4-5,0-LL; MOUSER# 651-1864451
J3: ESP-JTAG-2X05; 2X05_SHROUDED; MOUSER# 538-70246-1004; DIGIKEY# WM3478-ND
LED1: RX; CHIPLED_0805
LED2: TX; CHIPLED_0805
PCB1: LOLIN-D32
R1, R2: 68Ω; R0805; MOUSER# 652-CRM0805JW1R5ELF
R3: 120Ω; R0805; MOUSER# 652-CRM0805JW1R5ELF
SJ1: OPEN; SJ
SW1: Factory (5 sec); TE_1-1825910-4
U1: MAX3485CSA+; SO08; MOUSER# 700-MAX3485CSA

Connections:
3V3: C3.1, J3.1 (3V3), PCB1.3V3, U1.8 (VCC)
15V: D2.A, J2.1 (15V)
A: J2.2 (A), SJ1.2, U1.6 (A)
B: J2.3 (B), R3.1, U1.7 (B)
GND: C1.2, C2.2, C3.2, DC1.2 (GND), J2.4 (GND), J3.3 (GND), J3.5 (GND), J3.7 (GND), J3.9 (GND), PCB1.34 (I34), PCB1.GND, PCB1.GND@1 (GND), PCB1.GND@2 (GND), PCB1.VN (VN/I39), PCB1.VP (VP/I36), R1.1, R2.1, SW1.3, SW1.4, U1.5 (GND)
JTAG_!RST: J3.10 (NC), PCB1.RS (!RST/!JTAG_!RST)
JTAG_CK: J3.4 (TCK), PCB1.13 (IO13/JTAG_CK)
JTAG_DI: J3.8 (TDI), PCB1.12 (IO12/JTAG_DI)
JTAG_DO: J3.6 (TDO), PCB1.15 (IO15/JTAG_DO)
JTAG_MS: J3.2 (TMS), PCB1.14 (IO14/JTAG_MS)
unnamed: LED1.C, R1.2
unnamed: LED2.C, R2.2
unnamed: PCB1.0 (IO0), SW1.1, SW1.2
unnamed: R3.2, SJ1.1
RTS: PCB1.27 (RTS2/IO27), U1.2 (RE/), U1.3 (DE)
RX2: LED1.A, PCB1.25 (RX2/IO25), U1.1 (RO)
TX: LED2.A, PCB1.26 (TX2/IO26), U1.4 (DI)
VIN: C1.1, D2.C, DC1.1 (VIN)
VOUT: C2.1, DC1.3 (VOUT), PCB1.BAT

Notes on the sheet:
Up chip degugging JTAG
Pool Controller
bypass
Green
Amber

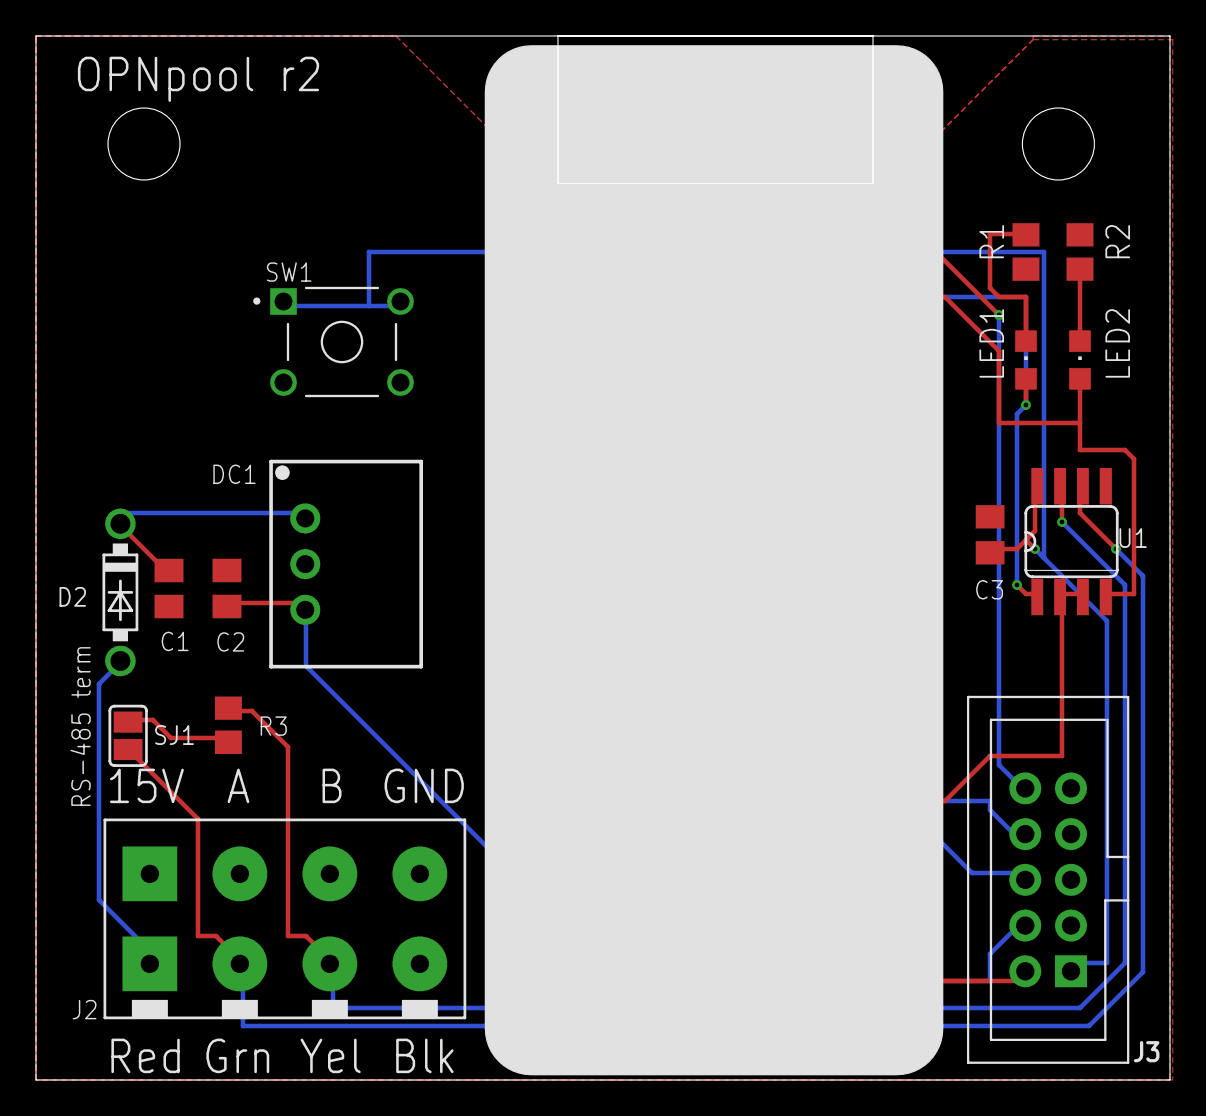
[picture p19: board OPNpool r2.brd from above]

Board: 2 copper layers, 63.0 x 58.0 mm, 16 parts (0 on the bottom side), 19 nets.

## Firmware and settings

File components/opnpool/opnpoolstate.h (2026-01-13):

#pragma once
#ifndef __cplusplus
# error "Requires C++ compilation"
#endif

#include <esp_system.h>
#include <freertos/FreeRTOS.h>
#include <freertos/semphr.h>
#include <cJSON.h>

#define MAGIC_ENUM_RANGE_MIN 0
#define MAGIC_ENUM_RANGE_MAX 256
#include "magic_enum.h"

#include "network.h"
#include "network_msg.h"

namespace esphome {
namespace opnpool {

// Forward declarations instead of including ipc.h or FreeRTOS.h
struct ipc_t;

/**
 * @brief Pool state system information
 **/

typedef struct poolstate_time_t {
    uint8_t  hour;
    uint8_t  minute;
} poolstate_time_t;

typedef struct poolstate_date_t {
    uint8_t   day;
    uint8_t   month;
    uint16_t  year;
} poolstate_date_t;

typedef struct poolstate_tod_t {
    poolstate_date_t  date;
    poolstate_time_t  time;
} poolstate_tod_t;

typedef struct poolstate_version_t {
    uint8_t  major;
    uint8_t  minor;
} poolstate_version_t;

typedef struct poolstate_system_t {
    poolstate_tod_t      tod;
    poolstate_version_t  version;
} poolstate_system_t;

enum class poolstate_elem_system_typ_t : uint8_t {
    TIME         = 0,
    CTRL_VERSION = 1,
    IF_VERSION   = 2
};


/**
 * @brief Pool state thermostat types
 **/

enum class poolstate_thermo_typ_t : uint8_t {
    POOL = 0,
    SPA  = 1
};

#ifdef __INTELLISENSE__
#define POOLSTATE_THERMO_TYP_COUNT (2)   // IntelliSense doesn't evaluate constexpr functions, use temporary constant
#else
#define POOLSTATE_THERMO_TYP_COUNT (poolstate_thermo_type_count())
#endif

constexpr size_t poolstate_thermo_type_count() {
    return magic_enum::enum_count<poolstate_thermo_typ_t>();
}

inline const char * poolstate_str_thermo_str(poolstate_thermo_typ_t const thermostat_id) {
    auto name = magic_enum::enum_name(thermostat_id);
    return name.data();
}

inline int poolstate_str_thermo_nr(char const * const thermostat_str) {
    auto value = magic_enum::enum_cast<poolstate_thermo_typ_t>(thermostat_str);
    return value.has_value() ? static_cast<int>(*value) : -1;
}

typedef struct poolstate_thermo_t {
    uint8_t  temp;
    uint8_t  set_point;
    uint8_t  heat_src;
    bool     heating;
} poolstate_thermo_t;

enum class poolstate_elem_thermos_typ_t : uint8_t {
    TEMP      = 0,
    SET_POINT = 1,
    HEAT_SRC  = 2,
    HEATING   = 3
};


/**
 * @brief Pool state schedule
 **/

enum class poolstate_elem_sched_typ_t : uint8_t {
    START = 0,
    STOP = 1
};

typedef struct poolstate_sched_t {
    bool      active;
    uint16_t  start;
    uint16_t  stop;
} poolstate_sched_t;


/**
 * @brief Pool state temperature types
 **/

enum class poolstate_temp_typ_t : uint8_t {
    AIR = 0,
    WATER = 1
};

#ifdef __INTELLISENSE__
#define POOLSTATE_TEMP_TYP_COUNT (2)   // IntelliSense doesn't evaluate constexpr functions, use temporary constant
#else
#define POOLSTATE_TEMP_TYP_COUNT (poolstate_temp_typ_count())
#endif

constexpr size_t poolstate_temp_typ_count() {
    return magic_enum::enum_count<poolstate_temp_typ_t>();
}

inline const char * poolstate_str_temp_str(poolstate_temp_typ_t const temp_id) {
    auto name = magic_enum::enum_name(temp_id);
    return name.data();
}

inline int poolstate_str_temp_nr(char const * const temp_str) {
    auto value = magic_enum::enum_cast<poolstate_temp_typ_t>(temp_str);
    return value.has_value() ? static_cast<int>(*value) : -1;
}

typedef struct poolstate_temp_t {
    uint8_t temp;
} poolstate_temp_t;

enum class PoolstateElemTempTyp : uint8_t {
    TEMP = 0
};


/**
 * @brief Pool state mode bit set
 **/

typedef struct poolstate_modes_t {
    bool  is_set[network_pool_mode_count()];  // IntelliSense flags this incorrectly - it compiles fine
} poolstate_modes_t;



/**
 * @brief Pool state circuits
 **/

typedef struct poolstate_circuits_t {
    bool     active[NETWORK_POOL_CIRCUIT_COUNT];  // IntelliSense flags this incorrectly - it compiles fine
    bool     delay[NETWORK_POOL_CIRCUIT_COUNT];   // IntelliSense flags this incorrectly - it compiles fine
} poolstate_circuits_t;

enum class poolstate_elem_circuits_typ_t : uint8_t {
    ACTIVE = 0,
    DELAY = 1
};


/**
 * @brief Pool state pump
 **/

typedef struct poolstate_pump_t {
    poolstate_time_t time;
    uint8_t          mode;
    bool             running;
    uint8_t          state;
    uint16_t         power;
    uint16_t         flow;
    uint16_t         speed;
    uint16_t         level;
    uint8_t          error;
    uint8_t          timer;
} poolstate_pump_t;

enum class poolstate_elem_pump_typ_t : uint8_t {
    TIME = 0,
    MODE = 1,
    RUNNING = 2,
    STATE = 3,
    POWER = 4,
    FLOW = 5,
    SPEED = 6,
    LEVEL = 7,
    ERROR = 8,
    TIMER = 9
};


/**
 * @brief Pool state chlorinator
 **/

enum class poolstate_chlor_status_t : uint8_t {
    OK = 0,
    LOW_FLOW = 1,
    LOW_SALT = 2,
    HIGH_SALT = 3,
    COLD = 4,
    CLEAN_CELL = 5,
    OTHER = 6
};

inline const char * poolstate_str_chlor_status_str(poolstate_chlor_status_t const chlor_state_id) {
    auto name = magic_enum::enum_name(chlor_state_id);
    return name.data();
}

inline int poolstate_str_chlor_status_nr(char const * const chlor_status_str) {
    auto value = magic_enum::enum_cast<poolstate_chlor_status_t>(chlor_status_str);
    return value.has_value() ? static_cast<int>(*value) : -1;
}

typedef struct poolstate_chlor_t {
    char                      name[sizeof(network_msg_chlor_name_str_t) + 1];
    uint8_t                   level;
    uint16_t                  salt;
    poolstate_chlor_status_t  status;
} poolstate_chlor_t;

enum class poolstate_elem_chlor_typ_t : uint8_t {
    NAME   = 0,
    LEVEL  = 1,
    SALT   = 2,
    STATUS = 3
};


/**
 * @brief Pool state structure containing all pool state information
 **/

typedef struct poolstate_t {
    poolstate_system_t    system;
    poolstate_temp_t      temps[POOLSTATE_TEMP_TYP_COUNT];
    poolstate_thermo_t    thermos[POOLSTATE_THERMO_TYP_COUNT];
    poolstate_sched_t     scheds[NETWORK_MSG_CTRL_SCHED_COUNT];
    poolstate_modes_t     modes;
    poolstate_circuits_t  circuits;
    poolstate_pump_t      pump;
    poolstate_chlor_t     chlor;
} poolstate_t;

enum class poolstate_elem_typ_t : uint8_t {
    SYSTEM = 0x00,
    TEMP = 0x01,
    THERMO = 0x02,
    SCHED = 0x03,
    CIRCUITS = 0x04,
    PUMP = 0x05,
    CHLOR = 0x06,
    MODES = 0x07,
    ALL = 0x08
};

typedef char * poolstate_get_value_t;
typedef struct poolstate_get_params_t {
    poolstate_elem_typ_t elem_typ;
    uint8_t          elem_sub_typ;
    uint8_t const    idx;
} poolstate_get_params_t;


/**
 * @brief Class representing the current state of the pool system
 **/    

     // forward declaration of OpnPool class
class OpnPool;
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

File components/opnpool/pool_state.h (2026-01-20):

#pragma once
#ifndef __cplusplus
# error "Requires C++ compilation"
#endif

#include <esp_system.h>
#include <esp_types.h>
#include <freertos/FreeRTOS.h>
#include <freertos/semphr.h>
#include <cJSON.h>

#define MAGIC_ENUM_RANGE_MIN 0
#define MAGIC_ENUM_RANGE_MAX 256
#include "magic_enum.h"
#include "network.h"
#include "network_msg.h"

namespace esphome {
namespace opnpool {

    // forward declarations (to avoid circular dependencies)
struct ipc_t;

struct poolstate_time_t {
    uint8_t  hour;
    uint8_t  minute;
};

struct poolstate_date_t {
    uint8_t   day;
    uint8_t   month;
    uint16_t  year;
};

struct poolstate_tod_t {
    poolstate_date_t  date;
    poolstate_time_t  time;
};

struct poolstate_version_t {
    uint8_t  major;
    uint8_t  minor;
};

struct poolstate_system_t {
    poolstate_tod_t      tod;
    poolstate_version_t  version;
};

enum class poolstate_elem_system_typ_t : uint8_t {
    TIME         = 0,
    CTRL_VERSION = 1,
    IF_VERSION   = 2
};

enum class poolstate_thermo_typ_t : uint8_t {
    POOL = 0,
    SPA  = 1
};

struct poolstate_thermo_t {
    uint8_t              temp_in_f;
    uint8_t              set_point_in_f;
    network_heat_src_t   heat_src;
    bool                 heating;
};

enum class poolstate_elem_thermos_typ_t : uint8_t {
    TEMP      = 0,
    SET_POINT = 1,
    HEAT_SRC  = 2,
    HEATING   = 3
};

enum class poolstate_elem_sched_typ_t : uint8_t {
    START = 0,
    STOP  = 1
};

struct poolstate_sched_t {
    bool      active;
    uint16_t  start;
    uint16_t  stop;
};

enum class poolstate_temp_typ_t : uint8_t {
    AIR   = 0,
    WATER = 1
};

struct poolstate_temp_t {
    uint8_t temp;
};

enum class PoolstateElemTempTyp : uint8_t {
    TEMP = 0
};

struct poolstate_modes_t {
    bool  is_set[enum_count<network_pool_mode_bits_t>()];  // IntelliSense flags this incorrectly
};

struct poolstate_circuits_t {
    bool  active[enum_count<network_pool_circuit_t>()];  // IntelliSense flags this incorrectly
    bool  delay[enum_count<network_pool_circuit_t>()];   // IntelliSense flags this incorrectly
};

enum class poolstate_elem_circuits_typ_t : uint8_t {
    ACTIVE = 0,
    DELAY = 1
};


struct poolstate_pump_t {
    poolstate_time_t     time;
    network_pump_mode_t  mode;
    bool                 running;
    network_pump_state_t state;
    uint16_t             power;
    uint16_t             flow;
    uint16_t             speed;
    uint16_t             level;
    uint8_t              error;
    uint8_t              timer;
};

enum class poolstate_chlor_status_t : uint8_t {
    OK         = 0,
    LOW_FLOW   = 1,
    LOW_SALT   = 2,
    HIGH_SALT  = 3,
    COLD       = 4,
    CLEAN_CELL = 5,
    OTHER      = 6
};

struct poolstate_chlor_t {
    char                      name[sizeof(network_msg_chlor_name_str_t) + 1];
    uint8_t                   level;
    uint16_t                  salt;
    poolstate_chlor_status_t  status;
};

/**
 * @brief Complete pool state structure for the pool automation system.
 *
 * This structure contains the full state of the pool system, including:
 * - System information (date, time, firmware version)
 * - Temperature readings (air, water)
 * - Thermostat states (pool, spa)
 * - Schedules for each circuit
 * - Mode bitsets
 * - Circuit states (active, delay)
 * - Pump status (mode, running, power, etc.)
 * - Chlorinator status (name, level, salt, status)
 *
 * @var system   System information (date, time, firmware version)
 * @var temps    Array of temperature readings (e.g., air, water)
 * @var thermos  Array of thermostat states (pool, spa)
 * @var scheds   Array of schedules for each circuit
 * @var modes    Mode bitsets (which pool modes are active)
 * @var circuits Circuit states (active/delay for each circuit)
 * @var pump     Pump status (mode, running, power, speed, etc.)
 * @var chlor    Chlorinator status (name, level, salt, status)
 */
struct poolstate_t {
    bool                  valid;
    poolstate_system_t    system;
    poolstate_temp_t      temps[enum_count<poolstate_temp_typ_t>()];
    poolstate_thermo_t    thermos[enum_count<poolstate_thermo_typ_t>()];
    poolstate_sched_t     scheds[enum_count<network_pool_circuit_t>()];
    poolstate_modes_t     modes;
    poolstate_circuits_t  circuits;
    poolstate_pump_t      pump;
    poolstate_chlor_t     chlor;
};

enum class poolstate_elem_typ_t : uint8_t {
    SYSTEM   = 0x00,
    TEMP     = 0x01,
    THERMO   = 0x02,
    SCHED    = 0x03,
    CIRCUITS = 0x04,
    PUMP     = 0x05,
    CHLOR    = 0x06,
    MODES    = 0x07,
    ALL      = 0x08
};

/**
 * @brief Class representing the current state of the pool system
 **/    

     // forward declaration of OpnPool class
class OpnPool;

class PoolState {

    public:
        PoolState(OpnPool * const parent) : parent_{parent} {}
        ~PoolState() {}

        void set(poolstate_t const * const state) {
            memcpy(&last_poolstate_, state, sizeof(poolstate_t));
            last_poolstate_.valid = true;
        }
        esp_err_t get(poolstate_t * const state) {
            if (!last_poolstate_.valid) {
                return ESP_ERR_INVALID_STATE;
            }
            memcpy(state, &last_poolstate_, sizeof(poolstate_t));
            return ESP_OK;
        }

        bool has_changed(poolstate_t const * const state) {
            if (!last_poolstate_.valid) {  // redundant check
                return true;
            }   
            return memcmp(&last_poolstate_, state, sizeof(poolstate_t)) != 0;
        }


    private:
        OpnPool * const parent_;
        poolstate_t last_poolstate_ = { .valid = false };
        
};

}  // namespace opnpool
}  // namespace esphome

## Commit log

2026-01-03 use native UART
2026-01-03 add device class to analog sensors
2026-01-06 log msgs from datalink_rx.cpp are now showing up after adding the apparently missing #include "esphome/core/log.h"
    [opnpool.cpp]
2026-01-06 fix crash in case IPC_TO_HOME_TYP_PUBLISH_DATA_DBG
    [opnpool.cpp]
2026-01-07 prevent *(null) read, by change network_msg_t to have a bytes[0] member instead of *bytes.
    [opnpool.cpp]
2026-01-08 Implement IPC switch command forwarding to pool_task
    - Extended OpnPoolSwitch with parent pointer and circuit_id
    - Implemented OpnPool::on_switch_command() to allocate and send network_msg_ctrl_circuit_set_t via IPC
    - Updated pool_task to handle MSG_TYP_CTRL_CIRCUIT_SET messages and convert to datalink packets
    - Wired up switches in __init__.py with parent and circuit_id mapping
2026-01-09 undo a bunch of Copilot PR. First time setting circuit works
2026-01-09 switch DATALINK_ADDRGROUP to magic enum
2026-01-12 add logic to report "switch changed" back to HA
2026-01-12 add other sensors to report to HA
2026-01-13 rm pump_status, aux1_sched, aux2_sched. rm opnpoolstate_get.cpp. rm poolstate_elem_modes_typ_t
2026-01-13 rm uart dependency
2026-01-14 fix schedule reporting, and climate entities
    [opnpool.cpp]
2026-01-18 remove COUNT from generated enum classes to fix OOB exception.
    [opnpool.cpp]
2026-01-19 map the mapping from SwitchId to network_circuit explicit
2026-01-19 combine the two heat_src defs
2026-01-19 fix for not all switches not reporting back
2026-01-20 fix dump of sensors
    [opnpool.cpp]
2026-01-20 add hardware
    [OPNpool r1.brd, OPNpool r1.sch, OPNpool r2.brd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]
2026-01-20 rm obsolete
    [OPNpool r1.brd, OPNpool r1.sch, Pool Interface (FEATHER-ESP8266).sch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]
2026-01-21 fix compile warnings at -Wall -Wextra level
    [opnpool.cpp]
2026-01-26 switch to esp32-c6-devkitc-1 module
    [OPNpool r4.brd, OPNpool r4.sch]
2026-01-26 switch to esp32-c6-devkitc-1 module #2
2026-01-27 create option for 2nd pump
2026-01-30 esp32c6 boards work. add return code checks.
2026-01-30 mv pump primary_pump; add cleanup; make single threaded more clear
2026-01-30 rm collosal switch() statements in network_rx; cleanup network_msg
2026-01-31 refractor; fix prevent memory leak on allocation failure
    [opnpool.cpp]
2026-02-02 prep for Matter over Thread support
    [partitions_matter.csv]
2026-02-02 Thread network transport is working (when enabled in yaml). Mater is waiting for native ESPHome support.
2026-02-02 bump partitions
    [partitions.csv, partitions_matter.csv]
2026-02-06 clean up pump msgs. refractor
2026-02-07 correct water/air temp reported to HA
    [opnpool.cpp]
2026-02-07 change air temp sensor input
2026-02-07 move to sub dir, step 1
    [partitions.csv]
2026-02-11 move dirs
    [partitions.csv]

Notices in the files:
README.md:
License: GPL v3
